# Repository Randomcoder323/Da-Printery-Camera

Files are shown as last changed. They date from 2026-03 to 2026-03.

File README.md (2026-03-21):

# Da printery Camera

## What and Why?
Thsi is a cmaera timelapse project for my A1 mini to be able to take timelapse. Its powred by an esp32 which a limit switch connected to my computer, and a camera, powered by python code to take pcitrues on each layer! I made this camera timelapse module to be able to take cool timelapse of my prints with a way better camera than the 0.5 fps 240 quality camera on the a1 mini. I can also remotely monitor my print as an added bonus!

## How will I assemble this? 
I will print the limt siwtch mount and screw the switch in, then put it on the printer. Before this  I will solder the wires to the esp32. I will put the camera on the table so its stable and both the cmaera and esp32 to my computer. I will lastly run my code and adjust the printer gcode.

## Pictures and Assembly 
<p align="center">
  <br><br>
  <br><br>
  <br><br>
  <br><br>
  <br><br>
  
</p>

## BOM

| Item | Qty | Price | Link |
|---|-----|---|---|
| ESP32 CH340C | 1 | $3.32 | [Buy](https://www.aliexpress.us/item/3256804290552594.html) |
| Arced 21mm limit switch | 1 | $1.59 | [Buy](https://www.aliexpress.us/item/3256808047511109.html) |
| Camera module | 1 | $11.11| [Buy](https://www.aliexpress.us/item/3256810425121893.html) |
| 3D printed parts | 1 | N/A | Self printed |
| 64GB MicroSD card for the camera | 1 | $5.08 | [Buy](https://www.aliexpress.us/item/3256802611588453.html) |

**Total (after coupons): ~$21**

## Wiring and Code
The limit siwtch is goind to be connected to the esp 32 gpio pin and ground. The esp 32 will be connected to my computer, which will also be conencted to the camera as an external camera. Everything is going to be soldered and then wrapped in electric tape to give it a clean look. I really like how everything is clean and simple, as I made moutn for the limit switch and a box for the esp32 with wires.

<p align="center">
  
</p>

Code can be found under **[Capture.py](PC_Camera_Capture/capture.py)**, this is the code that will run on my computer. **[esp_firmware.ino](PC_Camera_Capture/esp_firmware.ino)**, this is code that will be flashed on the esp32, it will detect the push and work with the python file on my computer!

  **[Timelapse.gcode](PC_Camera_Capture/Timelapse.gcode)** to make the timelapse work in the slicer, there are isntructions at the top, but baiscally it will go in the each layer gcode

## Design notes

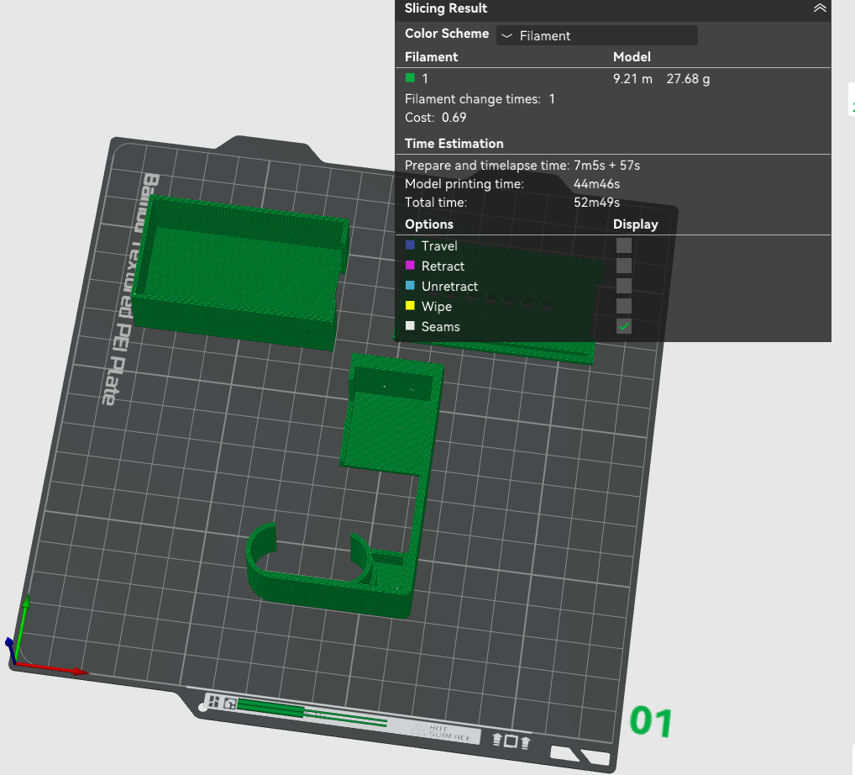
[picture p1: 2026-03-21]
CAD/slicer pic.png

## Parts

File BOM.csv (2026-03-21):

name | quantity | price | link
ESP 32 CH340C | 1 | 3.32 | https://www.aliexpress.us/item/3256804290552594.html?mp=1
Arced 21mm limit siwtch | 1 | 1.59 | https://www.aliexpress.us/item/3256808047511109.html?mp=1
Camera | 1 | 11.11 | https://www.aliexpress.us/item/3256810425121893.html?mp=1
3d print | 2 | 27 Grams I can cover it | Look in CAD folder for file and sliced image
Sd card 64 gb for camera | 1 | 5.08 | https://www.aliexpress.us/item/3256802611588453.html?mp=1
 |  | 21 after copouns

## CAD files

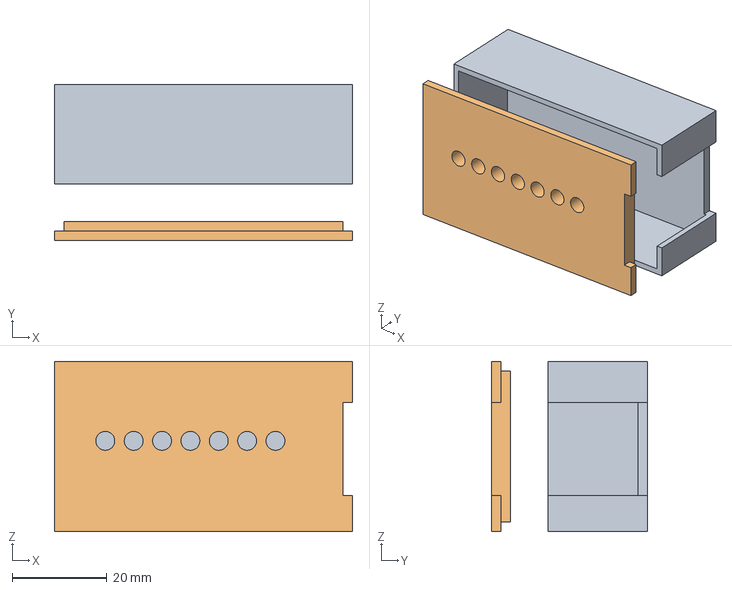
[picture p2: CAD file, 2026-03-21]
CAD/esp box inclosure.step
63.0 x 33.0 x 36.0 mm

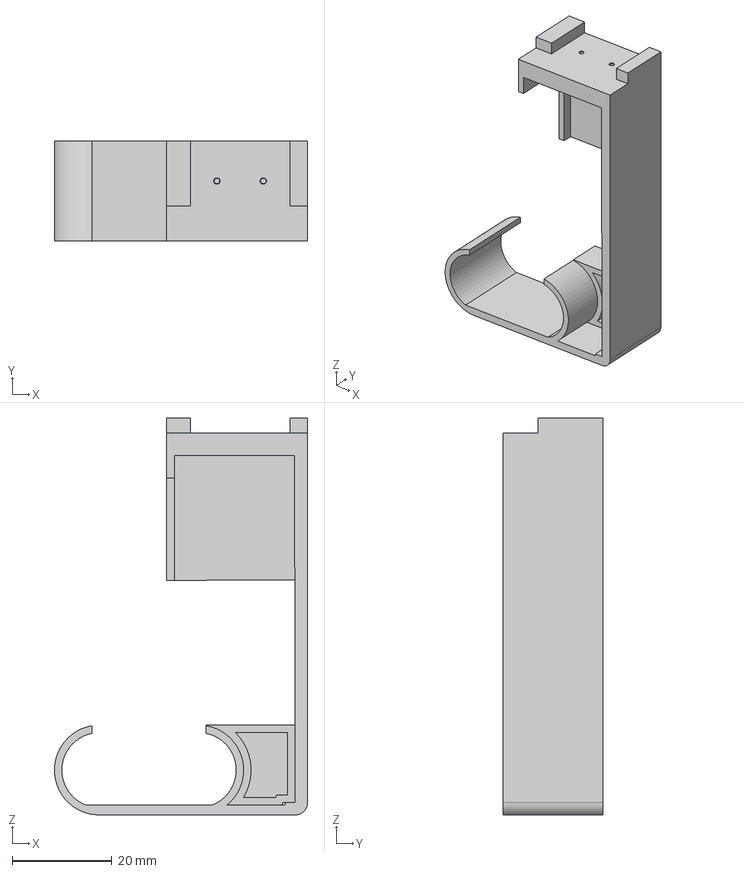
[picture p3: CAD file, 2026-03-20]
CAD/limit siwtch mount.step
50.7 x 20.0 x 79.5 mm

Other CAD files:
CAD/ALL f3d.f3d

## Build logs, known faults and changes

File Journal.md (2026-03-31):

# Da-Printery-Camera

# March 19 4:57 : Found Items on Aliepxress and made a visual diagram
I started by brainstroming idea for this project. I started by tring to figure out what ports I could use on my printer, I figured out that only the ams 4 pin port if free. I then knew that the only way was to connect it to my computer, which I'm fine with. I found a usb camera on alipress, for only about 10 dollars. I added that to the bom. I then found a micro controller, and esp32 with wifi and bluetooth. For my trigger sensor I'm using a limit switch to detect when the printer moves out the way. I then went onto canva, found image of the stuff I'm gonna use, and made a really helpful visual diagram. I choose a curved 21 mm switch for easier reach from the printer






**Total time spent: 0.7**

# March 19 5:38 : Limit Switch mount

Brfore starting anything I tried to find dimension online for the a1 mini and my limti switch I found some info online, but this was the most helpful! I then found some model online for the poop shot and got the neaurment for that from there. I started by building the outside diameted, with a circled side and the oval kidn shape for the poop shute holder.  I then started the bottom side of the mount and made the rectangular bottom and the plate at the bottom. . I then extruded everything and matche dthe heights. I then also made holder for the switch to be mounted with some screws. I added tolarances and a chamfer!










**Total time spent: 0.67**

# March 19 6:12 : Assembly in onshape

I started by exporting my parts and putting them into onshape. I took the limit siwtch name off of aliexpress and found a model online. I then found a really good a1 mini model online on reddit. I copied the onshape asssembly and added my part to the side. It was really dificult trying to the the mate connector to work but I got it. I then imported the limit switch, however I found no way to merge the bodies in assembly. I then had to mate connect all the parts which took a bit. I had to find the rigt way to mate connect it to the printer, but I then figured out that I could amte connect it then delete the connect and move it reigularly slight to manually adjust it. I will add the electronic box next journal!





**Total time spent: 0.5**

# March 20 7:46 AM : BOM and es 32 box+assembly.
I started by taking all thr components I needed and found the link in aliexpress. I put in the prices, and doubled checked that they are 1.what I needed, and 2. that they are the cheapest possible. I then cleaned it up so any one can follow it. I then found an esp32 model online, so I can get the mesurments and make sure it fits. I made the box around 1mm bigger, and made a lid with some good tolerances. I brought it into onshape and put the esp32 inside it, I really like how it looks. I will either add holes to the top or other side, so the wire has somewhere to go!










**Total time spent: 0.75**

# March 20 8:42pm : Code, wiring, and read.md

I started by making a quick demo wiring diagram on canva since its so simple with only two connections. The  esp32 will be connected to my coputer along with the cmaera. I started making the code with ( lots of help) from AI. I tried to learn and udnerstand what's going on and editing some of it myself. The code launches the camera,( which will later be the camera next to the printer when I build this), every time I press M it takes a picture and saves it, so the Idea is that when the printer hits the limit switch, the computer takes a picture from the camera, which will then save the picture. Herre is a quick demo video. I then started working on the readme.MD. I added the "Why" I made this project, wiring, but still need to add BOM and code.






[Watch the video](https://streamable.com/khbx4j)

**Total time spent: 0.6h**

# March 20 9:33pm : Finished Readme.MD, Added all files requried, checked submission

I started by adding the BOM in MD format, I then uploaded the missing assmebly files and made sure that all the files needed are there. I had to zip up the assembly file because It was too big. The a1 mini assembly model was not made by me, just used it for showing purposes. I went on to the reowkr website and made sure that I checked all the boxes. I just need to  add a simple gcode file and I should be good.




**Total time spent: 0.3h**

# March 20 9:48pm : Gcode, Slicer

I sliced the models in Bambu Studio, and added the grams to the BOM, It takes only 27 grams for the box and the mount. I then searched up some gcode commonly used fofr timelapses, and too kinspo from that. With a bit of help, I got a simple version. The way this  is gonna work is going to be that I add this gcode to the layer Gcode in the slicer, so after each layer it will go to this positon and hit the switch




**Total time spent: 0.2h**

# Total Time = 6.12 hours with build

# March 31 12:18pm : Buidling!

I started by opening all the pacages and making sure that they are the right ones, I recived the microsd card, eesp32, limit switch and camera. I downlaoded the app and setup the camera, however it wasn't deteceted on many pc for some reason. After downlaoding varoius software I learned that its using the usb cable for power only. I then found an online portal for the app where I can see the camera. So I changed the python code to take a screenshot instead of a picture from my webcam. I then sliced and printed the esp 32 case and switch mount. I took the .ino code and uplaoded it to the esp32 and it worked first try. I tested the code with my webcam and the screenshot code, and both worked flawlessly. After the stuff was printed I put the switch on the mount and tried it on the printer, and it fit perfectly. I put the esp32 in the box and everything fit. I them took the gcode I made and put it in the layer gcode. I set up the camera and made sure everything looked good and even tested it by moving the printer head. I started the pritn anf ran the python code, but it ddin't work quite well. First of all the head didn't move far left enough and it wasn't extruding properly, I tried troubleshooting for a bit but had no luck. I then edited te timelapse gcode to do what I want and it worked good. I then realized after it finsihed that the camera has a delay, meaning that the printer had clciked the button and the cmaera took a pciture when the head was still printing in the middle. I fixed this by making the head wwait 5 seconds on the side and the python code taking a screenshot after 3.5 second. I tried a couple takes and got it right. I took pictures and used an online tool to turn the frrames into actual video!











Watch the video (https://jumpshare.com/embed/5yQEPPPaGBSJYMsxx8vl)
**Total time spent: 2.4h**

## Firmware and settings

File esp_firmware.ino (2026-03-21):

const int limitSwitchPin = 32;

int buttonState;             
int lastButtonState = HIGH;   
unsigned long lastDebounceTime = 0;  
unsigned long debounceDelay = 50;    

void setup() {
  Serial.begin(115200);
  pinMode(limitSwitchPin, INPUT_PULLUP);
}

void loop() {
  int reading = digitalRead(limitSwitchPin);

  if (reading != lastButtonState) {
    lastDebounceTime = millis(); 
  }

  if ((millis() - lastDebounceTime) > debounceDelay) {
    if (reading != buttonState) {
      buttonState = reading;
      if (buttonState == LOW) {
        Serial.println("TRIGGER");
      }
    }
  }
  lastButtonState = reading;
}

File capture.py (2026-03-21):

import cv2
import serial
import time
import os

SERIAL_PORT = 'COM3'   
BAUD_RATE = 115200
CAMERA_INDEX = 0       
SAVE_FOLDER = 'timelapse_photos'

if not os.path.exists(SAVE_FOLDER):
    os.makedirs(SAVE_FOLDER)

ser = None
try:
    ser = serial.Serial(SERIAL_PORT, BAUD_RATE, timeout=0.01)
except Exception:
    pass

cap = cv2.VideoCapture(CAMERA_INDEX)
cap.set(cv2.CAP_PROP_FRAME_WIDTH, 1920)
cap.set(cv2.CAP_PROP_FRAME_HEIGHT, 1080)

if not cap.isOpened():
    exit(1)

photo_count = 0

while True:
    try:
        ret, frame = cap.read()
        if not ret:
            time.sleep(0.1)
            continue
            
        cv2.imshow("Camera", frame)
        
        key = cv2.waitKey(1) & 0xFF
        take_photo = False
        
        if key == ord('q'):
            break
        elif key == ord('g'):
            take_photo = True
            
        if ser and ser.in_waiting > 0:
            line = ser.readline().decode('utf-8').strip()
            if line == "TRIGGER":
                take_photo = True
                
        if take_photo:
            filename = os.path.join(SAVE_FOLDER, f"frame_{photo_count:05d}.jpg")
            cv2.imwrite(filename, frame)
            
            flash = frame.copy()
            flash[:] = (255, 255, 255)
            cv2.imshow("Camera", flash)
            cv2.waitKey(50)
            
            print(f"Captured {filename}")
            photo_count += 1
            
    except KeyboardInterrupt:
        break
    except Exception as e:
        time.sleep(1)

cap.release()
cv2.destroyAllWindows()
if ser is not None:
    ser.close()

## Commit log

2026-03-21 Rename wiper step.step to limit siwtch mount.step
    [limit siwtch mount.step]
2026-03-21 Rename BOM - Sheet1.csv to BOM.csv
    [BOM.csv]
2026-03-21 Rename ImageToStl.com_Full+Assembly.zip to Full Assembly_Zip_because it was too large.zip
